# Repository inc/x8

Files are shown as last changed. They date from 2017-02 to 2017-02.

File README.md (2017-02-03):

# X8 computer

## Overview

X8 is a small low-cost low-power computer designed by Lone Dynamics.

## Specifications

| | |
| --- | --- |
| Dimensions | 1in x 1in (25.4mm x 25.4mm) | | | |
| Processor | 8-bit ATmega328PB (2KB SRAM / 32KB Flash) @ 8MHz |
| Memory | 1Mb (128KB) SRAM via SPI @ 4MHz |
| Wireless | ESP-01 WiFi module via UART0 (optional) |
| Display | 128x64 OLED display module via I2C (optional) |
| Power | MicroUSB (1A onboard regulator) |

## Photos

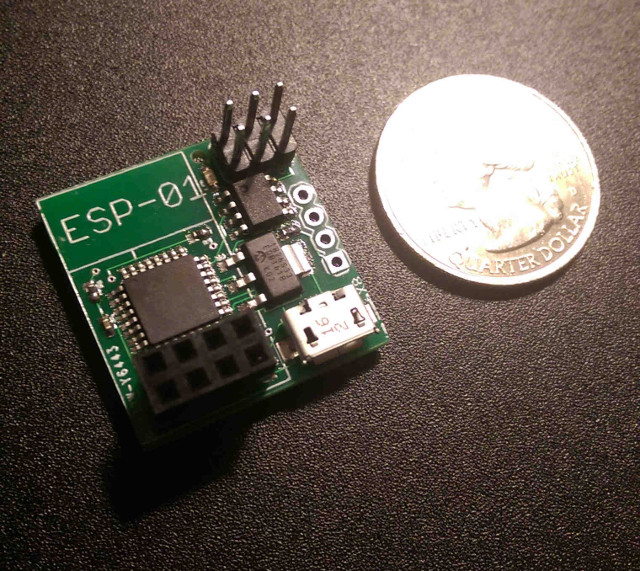
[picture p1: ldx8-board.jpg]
Board


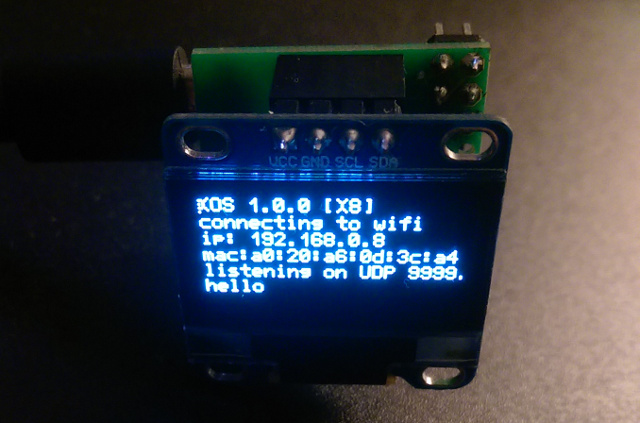
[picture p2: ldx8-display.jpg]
Display


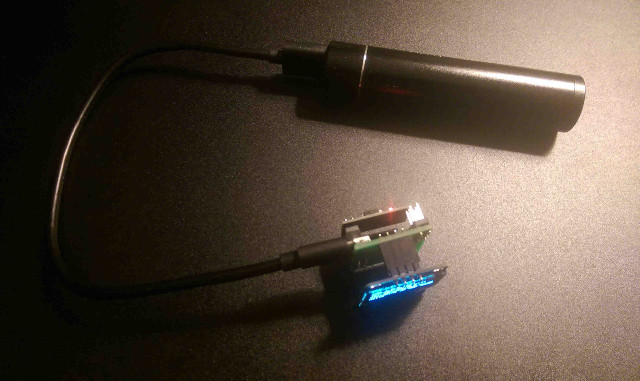
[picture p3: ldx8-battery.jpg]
Battery


## Pinout

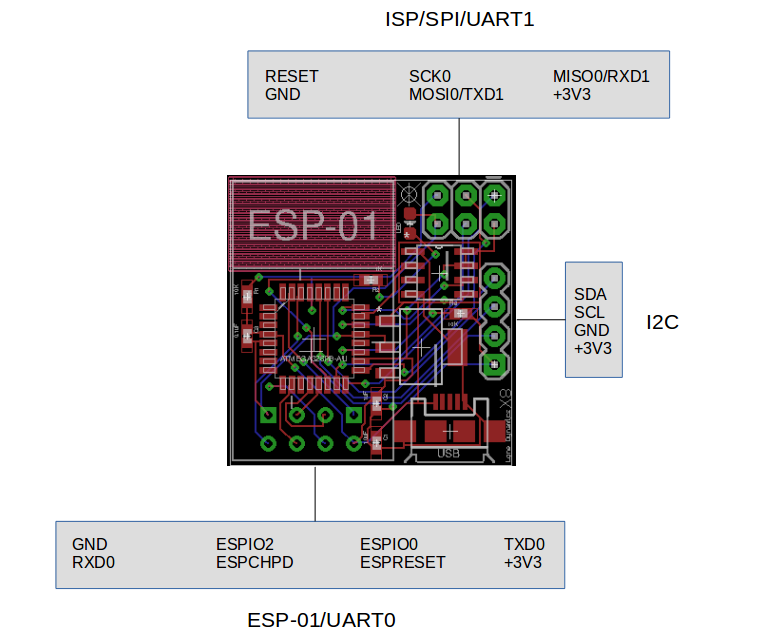
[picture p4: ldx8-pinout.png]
Pinout


## Schematics

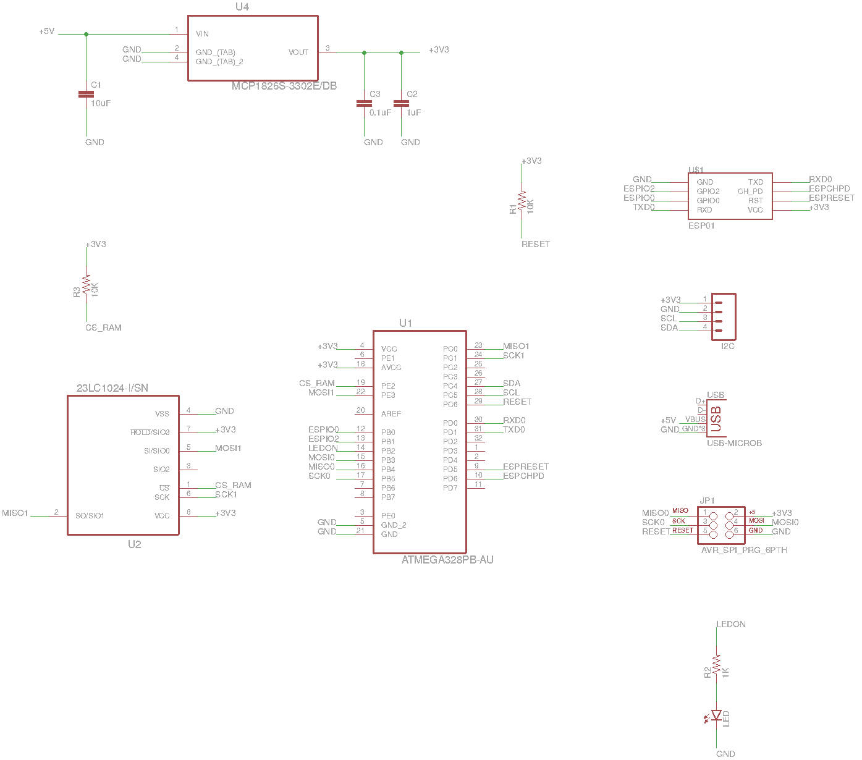
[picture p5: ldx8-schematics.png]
Schematics


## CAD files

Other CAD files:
x8.prt

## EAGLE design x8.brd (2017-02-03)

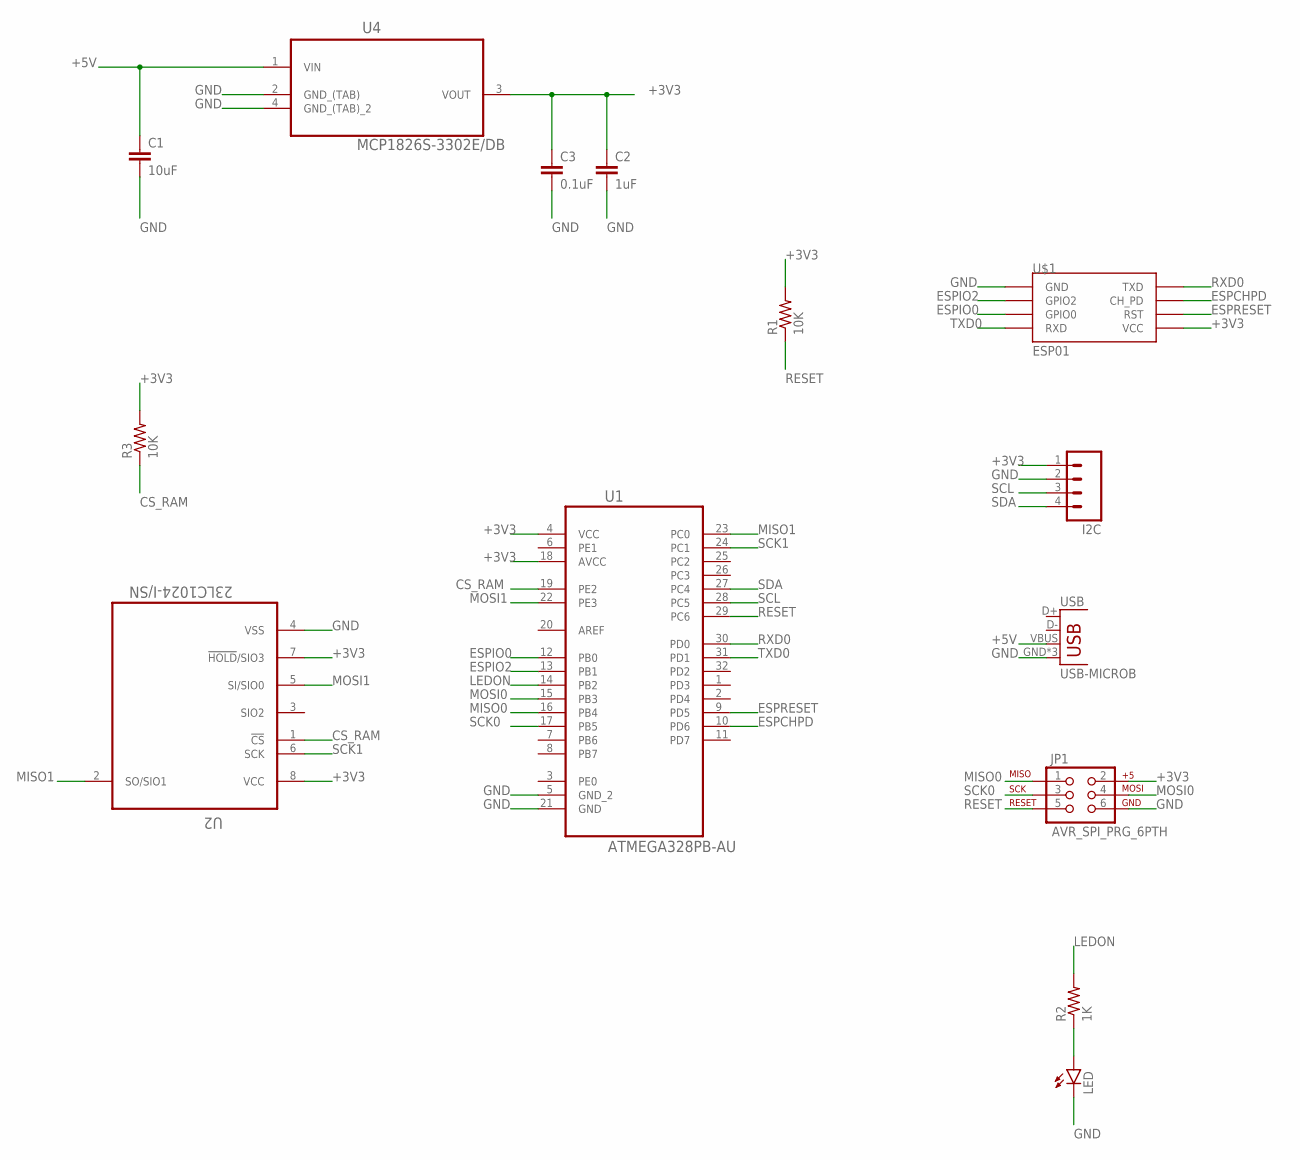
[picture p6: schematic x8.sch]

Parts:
C1: 10uF; 0402-CAP
C2: 1uF; 0402-CAP
C3: 0.1uF; 0402-CAP
I2C: M04PTH; 1X04
JP1: AVR_SPI_PRG_6PTH; 2X3
LED: LED0603; LED-0603
R1, R3: 10K; 0402-RES
R2: 1K; 0402-RES
U1: ATMEGA328PB-AU; QFP80P900X900X120-32N
U2: 23LC1024-I/SN; SOIC127P600X175-8N
U4: MCP1826S-3302E/DB; SOT230P700X180-4N
U$1: ESP01
USB: USB-MICROB

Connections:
+3V3: C2.1, C3.1, I2C.1, JP1.2, R1.2, R3.2, U1.4 (VCC), U1.18 (AVCC), U2.7 (!HOLD!/SIO3), U2.8 (VCC), U4.3 (VOUT), U$1.VCC
+5V: C1.1, U4.1 (VIN), USB.VBUS
CS_RAM: R3.1, U1.19 (PE2), U2.1 (!CS)
ESPCHPD: U1.10 (PD6), U$1.CH_PD
ESPIO0: U1.12 (PB0), U$1.GPIO0
ESPIO2: U1.13 (PB1), U$1.GPIO2
ESPRESET: U1.9 (PD5), U$1.RST
GND: C1.2, C2.2, C3.2, I2C.2, JP1.6, LED.C, U1.5 (GND_2), U1.21 (GND), U2.4 (VSS), U4.2 (GND_(TAB)), U4.4 (GND_(TAB)_2), U$1.GND, USB.GND, USB.MT1 (GND), USB.MT2 (GND)
LEDON: R2.2, U1.14 (PB2)
MISO0: JP1.1, U1.16 (PB4)
MISO1: U1.23 (PC0), U2.2 (SO/SIO1)
MOSI0: JP1.4, U1.15 (PB3)
MOSI1: U1.22 (PE3), U2.5 (SI/SIO0)
unnamed: LED.A, R2.1
RESET: JP1.5, R1.1, U1.29 (PC6)
RXD0: U1.30 (PD0), U$1.TX (TXD)
SCK0: JP1.3, U1.17 (PB5)
SCK1: U1.24 (PC1), U2.6 (SCK)
SCL: I2C.3, U1.28 (PC5)
SDA: I2C.4, U1.27 (PC4)
TXD0: U1.31 (PD1), U$1.RX (RXD)

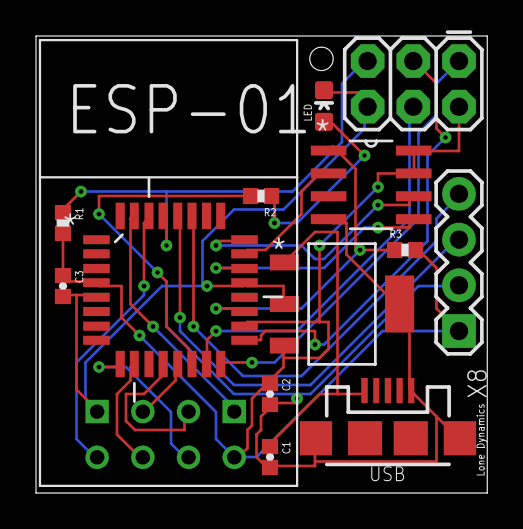
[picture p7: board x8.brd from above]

Board: 2 copper layers, 25.1 x 25.4 mm, 14 parts (0 on the bottom side), 21 nets.

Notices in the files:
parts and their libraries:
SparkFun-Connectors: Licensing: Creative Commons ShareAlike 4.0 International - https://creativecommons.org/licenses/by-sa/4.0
